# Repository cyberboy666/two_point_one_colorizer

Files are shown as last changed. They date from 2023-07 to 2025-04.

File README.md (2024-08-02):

# two_point_one_colorizer

### analog video colorize effect - adapted from a rob schafer design



- this circuit is distributed by __UNDERSCORES__ - _an open video hardware label_ : it is available to purchase - as a pcb, kit or assembled unit - at [underscores.shop](https://underscores.shop/two_point_one_colorizer/)
- the schematic for the circuit can be found [here](/hardware/schematic.pdf)
- the pcb gerber files for the lastest version can be found [here](/hardware/gerber_latest.zip)
- interactive BOM is [here](https://htmlpreview.github.io/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)
- consider [donating](https://opencollective.com/underscores) to the underscores project to help us continue creating for the commons

## demo video

(https://videos.scanlines.xyz/w/naCDtL88vypcoSo1NTCry6)

## background

<details>
<summary>background</summary>

Rob Schafer designed the original version of this circuit and shared it online in 2020.

It was updated and adapted to pcb by cyberboy666 as open-source hardware with help from the scanlines community – changes included adding PAL, extra color controls and switching to parts that are cheaper & more available









robs original circuit,  effect shown and the schematic here 

</details>
  
# documentation

this project is fully _open-source hardware_ - all the files required to build it are included in this repo for free. if you have the time and/or skill you can contribute back by collaborating on / testing new designs, improving these docs, making demo videos/other creative content etc. you can also support the project financially by [donating](https://opencollective.com/underscores) directing, or purchasing through the [web shop](https://underscores.shop).

depending on whether you are going fully diy or buying an assembled and tested unit, some of the following guides will be relavent to you. the flow would be:

## ordering parts

<details><summary><b>parts sourcing guide (w/ notes on pcb fabracation )</b> - start here if you are building fully from scatch or have purchased a pcb</summary>

i try to source all the parts i can from either:
- [tayda](https://www.taydaelectronics.com/) ; cheaper for common parts like resistors etc, also good for mechanical parts like switches and buttons
- [mouser](https://www.mouser.de/) ; has lots more options, speciality video ic's, can sometimes cost more (free shipping on orders over 50euros)
- other ; ocationally there will be parts which will need to be sourced elsewhere - usaully either aliexpress, ebay or amazon etc...

take a look at the [full_bom](/hardware/bom/full_bom.csv) for this project to see where i am sourcing each part from

## import into tayda

- go to the [tayda quick order](https://www.taydaelectronics.com/quick-order/) and in bottom corner choose _add from file_
- select the file [tayda_bom.csv](./hardware/bom/tayda_bom.csv) in the BOM folder (you will have to download it first or clone this repo)
- after importing select _add to cart_
- __NOTE:__ the minimum value for resistors is 10, so you may need to modify these values to add to cart (or if they are already modified here you will need to see the  full_bom for actual part QTY) 

- OPTIONAL: it is a good idea to add some dip-ic sockets and 2.54pin headers/sockets to your tayda order if you dont have them around already
  
## import into mouser

- go to [mouser bom tool](https://nz.mouser.com/Bom/) and click _upload spreadsheet_
- select the file [mouser_bom.csv](./hardware/bom/mouser_bom.csv) in this folder (you will have to download it first or clone this repo), then _upload my spreadsheet_ and _next_
- ensure that __Mouser Part Number__ is selected in the dropdown above the first row, then _next_, _process_
- if everything looks correct can now put _add to basket_

# ordering pcbs

you can support this project by buying individual pcbs from the [shop](https://underscores.shop). if you would rather have pcbs fabricated from gerbers directly the file you need is [here](/hardware/gerber_latest.zip)

- i get my pcbs fabricated from [jlcpcb](https://cart.jlcpcb.com/quote) - 5 is the minumum order per design
- upload the zip file with the `add gerber file` button
- the default settings are mostly fine - set the __PCB Qty__ and __PCB Color__ settings (you can check that the file looks correct with pcb veiwer)
- it may be best to combine orders with other pcbs you want to have fab'd since the shipping can cost more than the items - also orginising group buys is a good way to distribute the extra pcbs /costs 
  
i often use jlcpcb because they are reliable, cheap and give you an option of colours. remember though that the cheapest Chinese fab houses are not always the most ethical or environmently friendly - if you can afford it consider supporting local companies. 

  </details>
  
## assembly guide
  
<details><summary><b>assembly guide</b> - start here if you have purchased a diy kit</summary>

## interactive BOM for build guiding

follow this link to view the [interactive BOM](https://htmlpreview.github.io/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)

## general solder advice

- remember to heat pad first (2-3seconds), then add solder, then continue to heat (1-2seconds)

- Checkout the web-comic [soldering is easy](https://mightyohm.com/files/soldercomic/FullSolderComic_EN.pdf) for more soldering advice

## general order of assembly

- in general while assembling i start placing resistors and capacitors first. placing 5 - 10 components at a time and then flipping the board to solder them and trim the legs etc.
- next i would do diodes, transistors and ic's - taking care that these are placed in the right direction (using a ic socket can be useful)
- finally i place the interface parts - rca jacks, power jack, pots and switches - make sure these have lots of solder on for structural stablity

</details>

## operating guide
  
<details><summary><b>operating guide</b> - start here if you have purchased an assembled unit</summary>



To set up using the circuit plug an active video source into composite video input and a display into composite video output (test input/outputs by toggling signal bypass switch first to ensure they are working as expected)

Next plug in a 5v center-positive power supply into the 2.1mm barrel jack connector – I like to use a usb wall charger for this – and toggle off the bypass

Adjusting the level knobs should change the resulting image – adjusting the three color knobs and one color switch should set the color and shade for that level

The color_both in middle should off-set resulting color of both sides at once. Playing with format and alternating lines slide switches can help achieve glitching and out of spec colors also

</details>

### more info

<details><summary><b>how the circuit works</b></summary>
  
[coming soon]
                                                                                                                             
</details>

<details><summary><b>contributing guide</b></summary>
  
if you would like to contribute back to these projects in some way but dont know how the best thing (for now) would be to reach out to me directly ( tim@cyberboy666.com or @cyberboy666 on scanlines forum) - i will be happy to help
  
</details>

## credits & more info

This circuit is distributed through UNDERSCORES – open video hardware label – visit [underscores.shop](https://underscores.shop) for more info

The pcb was designed using KICAD , the booklet was created in LibreOffice Draw

Everything from gerbers, cad files, panels and documentation is freely available online and distributed under CC-BY-SA / open-source licenses – help us contribute to the commons !

Ask any questions or start discussions related to this project on the [scanlines.xyz](https://scanlines.xyz) forum – an online community space dedicated to diy av / electronic media art

You can contact me directly at tim (at) cyberboy666 (dot) com 
Please get in touch if you are interested in hosting a workshop !



Thanks to Rob Schafer for sharing your designs and knowledge. to Bastien Lavaud for circuit advice, always. To Ben Caldwell for project advice. To everyone who has or will contribute ♥♥♥

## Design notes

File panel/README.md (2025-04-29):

# enclosure guide

we now offer two kinds of enclosures for this project:

- __stand-alone enclosure__ - made from a front and back panel, plus screws and standoffs



- __eurorack enclosure__ - made from just a front panel, plus screws and standoffs to mount in a eurorack case



you can support these projects by getting enclosure kits directly through [underscores.shop](https://underscores.shop) - [standalone](https://underscores.shop/product/standalone-enclosure-kit-for-two_point_one_colorizer/) and [eurorack](https://underscores.shop/product/eurorack-kit-for-two_point_one_colorizer/) - _if ordered with an assembled unit we will also assemble the enclosure for you also_

# diy part sourcing

## panel fabrication

included in this repo are the cad files needed to create your own panels. they are designed in kicads pcbnew - so open the `.kicad_pcb` file to edit them directly. 

you can also use the exported `gerber` files (here they are combined in `.zip`) to get panels fabricated in __fr4__ at a pcb house like the ones we sell. (these usually have a minimum order of 5 or 10)  

another option for diy fabrication is using a lasercutter to cut the panels in wood or acrylic. this is what i do when prototyping panels so you should find some exports in `svg` or `dxf` that are laser ready. _note that the `edgecut` layer is for cutting out and the `silkscreen` layer is for the panel markings. you may need to edit these files or export directly from pcbnew to suit the cutter you are using_

it would also be possible to import these panel files into a sketch in 3d cad program like __freecad__ to create a 3d enclosure for 3d printing... however this is not something i have files prepared for

## 3d printing

i use some custom modelled switch and pot caps for my enclosure kits. you can print these yourself or upload them to a 3d printing fabrication service.

## enclosure kit BOM

things like screws and standoffs can be sourced from lots of places. i will link my source as an example although these links often expire. you could even 3d print your own standoffs from the _id/od_ and length (inner diameter 3.2mm, outer diameter 5mm)

### standalone enclosure

item | source
--- | ---
Front panel | [two_point_one_colorizer_v1_0_0_default_panel.zip](https://github.com/cyberboy666/two_point_one_colorizer/blob/main/panel/default_panel/two_point_one_colorizer_v1_0_0_default_panel.zip)
Back panel | [back_panel.zip](https://github.com/cyberboy666/two_point_one_colorizer/blob/main/panel/back_panel/back_panel.zip)
Rubber feet x4 | [aliexpress](https://www.aliexpress.com/item/1005005287385986.html?pdp_ext_f=%7B%22sku_id%22:%2212000032498489269%22%7D)
Pot cap x9 | 3d printed from [stl file](https://github.com/cyberboy666/enclosure_kit_commons/blob/main/cap_pot_6mm_shaft/cap_pot_star_single_r2.8.stl)
Switch cap x2 | 3d printed from [stl file](https://github.com/cyberboy666/enclosure_kit_commons/blob/main/cap_switch_1P2T_tayda_A-659/cap_switch_1P2T_tayda_A-659_single-cap.stl)
M3-25mm screw x4 | [aliexpress](https://www.aliexpress.com/item/1005002364189187.html?pdp_ext_f=%7B%22sku_id%22:%2212000020354274907%22%7D)
M3 nut x4 | [aliexpress](https://www.aliexpress.com/item/1005007502691265.html?pdp_ext_f=%7B"sku_id":"12000041089836836"%7D)
m3-12mm standoff x4 (front) | [aliexpress](https://www.aliexpress.com/item/1005003086579258.html?pdp_ext_f=%7B"sku_id":"12000023995222163"%7D)
m3-5mm standoff x4 (back) | [aliexpress](https://www.aliexpress.com/item/1005003086579258.html?pdp_ext_f=%7B"sku_id":"12000023995222156"%7D)

### eurorack enclosure

item | source
--- | ---
Eurorack front panel | [two_point_one_colorizer_v1_0_0_eurorack_panel.zip](https://github.com/cyberboy666/two_point_one_colorizer/blob/main/panel/eurorack_panel/two_point_one_colorizer_v1_0_0_eurorack_panel.zip)
Eurorack 16pin power converter | [eurorack_to_usb_passive_mk_i.zip](https://github.com/cyberboy666/enclosure_kit_commons/blob/main/eurorack_power-adapters/eurorack_to_usb_passive/eurorack_to_usb_passive_mk_i.zip) gerber
Vertical barrel jack | [tayda](https://www.taydaelectronics.com/dc-power-jack-2-1mm-round-type-panel-mount-1.html)
Pot cap x2 | 3d printed from [stl file](https://github.com/cyberboy666/enclosure_kit_commons/blob/main/cap_pot_6mm_shaft/cap_pot_star_single_r2.8.stl)
Switch cap x2 | 3d printed from [stl file](https://github.com/cyberboy666/enclosure_kit_commons/blob/main/cap_switch_1P2T_tayda_A-659/cap_switch_1P2T_tayda_A-659_single-cap.stl)
M3-25mm screw x4 | [aliexpress](https://www.aliexpress.com/item/1005002364189187.html?pdp_ext_f=%7B%22sku_id%22:%2212000020354274907%22%7D)
M3 nut x4 | [aliexpress](https://www.aliexpress.com/item/1005007502691265.html?pdp_ext_f=%7B"sku_id":"12000041089836836"%7D)
m3-12mm standoff x4 (front) | [aliexpress](https://www.aliexpress.com/item/1005003086579258.html?pdp_ext_f=%7B"sku_id":"12000023995222163"%7D)
m3-8mm screw x4 | [aliexpress](https://www.aliexpress.com/item/1005002364189187.html?pdp_ext_f=%7B%22sku_id%22:%2212000020354274900%22%7D)

## eurorack power jack placement

many underscores circuits take 5v from a [horizontal mounted dc barrel jack](https://www.taydaelectronics.com/dc-power-jack-2-1mm-barrel-type-pcb-mount.html) which is good for standalone circuits powered from the side. however for eurorack mounted circuits it can be easier to plug in power from behind. in this case we can use a [vertical dc socket](https://www.taydaelectronics.com/dc-power-jack-2-1mm-round-type-panel-mount-1.html) instead. for these sockets the longer pin is GND which goes closest to the edge of pcb.

Screenshot from 2025-04-29 11-19-55



## enclosure assembling

these enclosures are assemlbed by creating a stack of front-panel -> circuit -> back-panel using the screws and standoffs. where the front standoffs go between front panel and pcb and back standoff go between back panel and pcb. the m3 hex holds it together from the bottom.

i find it easiest to hold circuit on its side and work around one screw at a time:

- first place the front standoff between front panel and pcb
- then put the screw through holding them together
- next place back standoff on screw followed by back panel and hex
- then repeat for other 3 corners

tweezers can be helpful to pick and place the standoffs and also to tighten the m3 hexs

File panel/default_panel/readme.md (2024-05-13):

# two_point_one_colorizer default_panel notes

- the mounting holes fit m3 screws
- 25mm screws will fit front_panel, pcb and back_plate
- the front_panel mounts to pcb with 12mm standoffs
- small slide switches to set pal/ntsc are too low to be hand switched with panel on - can still be set with tool such as screwdriver
- the default potentiometers in underscores BOMs have 12mm shaft lengths - consider replacing these with >17mm shaft length alternatives if you plan to use it with a panel

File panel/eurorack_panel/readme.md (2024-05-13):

# two_point_one_colorizer eurorack_panel notes

- the mounting holes fit m3 screws
- the panel mounts to pcb with 12mm standoffs
- this circuit is powered by 5v on 2.1_barrel_jack - a [vertical jack](https://www.taydaelectronics.com/dc-power-jack-2-1mm-round-type-panel-mount-1.html) soldered to bottom of pcb will allow powering from within eurorack case
- small slide switches to set pal/ntsc are too low to be hand switched with panel on - can set with tool such as screwdriver
- this panel is 20HP
- the default potentiometers in underscores BOMs have 12mm shaft lengths - consider replacing these with >17mm shaft length alternatives if you plan to use it with a panel

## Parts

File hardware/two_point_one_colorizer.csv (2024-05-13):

Reference | Quantity | Value | Footprint | Datasheet
C1 C3 | 2 | 33p | Capacitor_THT:C_Disc_D4.7mm_W2.5mm_P5.00mm
C14 | 1 | 100p | Capacitor_THT:C_Disc_D4.7mm_W2.5mm_P5.00mm
C18 C19 C20 C21 | 4 | 10p | Capacitor_THT:C_Disc_D4.7mm_W2.5mm_P5.00mm
C2 C5 C6 C7 C8 C9 C10 C11 C12 C13 C15 C16 C17 | 13 | 0.1u | Capacitor_THT:C_Disc_D4.7mm_W2.5mm_P5.00mm
C4 | 1 | 10u | Capacitor_THT:CP_Radial_D5.0mm_P2.50mm
D1 | 1 | 1n914 | Diode_THT:D_DO-41_SOD81_P7.62mm_Horizontal
J1 | 1 | Barrel_Jack | Connector_BarrelJack:BarrelJack_Horizontal
J2 J5 | 2 | rca | lib_fp:tht_vertical_rca | ~
Q1 | 1 | 2N3904 | Package_TO_SOT_THT:TO-92L_HandSolder | https://www.fairchildsemi.com/datasheets/2N/2N3904.pdf
R1 R5 R8 | 3 | 75 | Resistor_THT:R_Axial_DIN0207_L6.3mm_D2.5mm_P7.62mm_Horizontal
R12 | 1 | 680 | Resistor_THT:R_Axial_DIN0207_L6.3mm_D2.5mm_P7.62mm_Horizontal
R15 | 1 | 12k | Resistor_THT:R_Axial_DIN0207_L6.3mm_D2.5mm_P7.62mm_Horizontal
R17 R18 | 2 | 18k | Resistor_THT:R_Axial_DIN0207_L6.3mm_D2.5mm_P7.62mm_Horizontal
R19 R20 | 2 | 22k | Resistor_THT:R_Axial_DIN0207_L6.3mm_D2.5mm_P7.62mm_Horizontal
R2 R4 | 2 | 1m | Resistor_THT:R_Axial_DIN0207_L6.3mm_D2.5mm_P7.62mm_Horizontal
R23 R24 | 2 | 82k | Resistor_THT:R_Axial_DIN0207_L6.3mm_D2.5mm_P7.62mm_Horizontal
R10 R13 R14 R25 R26 | 5 | 10k | Resistor_THT:R_Axial_DIN0207_L6.3mm_D2.5mm_P7.62mm_Horizontal
R27 R28 R29 R30 | 4 | 2.7k | Resistor_THT:R_Axial_DIN0207_L6.3mm_D2.5mm_P7.62mm_Horizontal
R3 | 1 | 5.1k | Resistor_THT:R_Axial_DIN0207_L6.3mm_D2.5mm_P7.62mm_Horizontal
R16 R33 R35 | 3 | 1.5k | Resistor_THT:R_Axial_DIN0207_L6.3mm_D2.5mm_P7.62mm_Horizontal
R34 R36 | 2 | 3.3k | Resistor_THT:R_Axial_DIN0207_L6.3mm_D2.5mm_P7.62mm_Horizontal
R6 | 1 | 100 | Resistor_THT:R_Axial_DIN0207_L6.3mm_D2.5mm_P7.62mm_Horizontal
R7 R11 R31 R32 | 4 | 1k | Resistor_THT:R_Axial_DIN0207_L6.3mm_D2.5mm_P7.62mm_Horizontal
R9 | 1 | 680k | Resistor_THT:R_Axial_DIN0207_L6.3mm_D2.5mm_P7.62mm_Horizontal
RV1 | 1 | 20k_pot | lib_fp:Potentiometer_Vertical_Large
RV2 RV3 RV4 RV5 RV6 RV7 | 6 | 10k_pot | lib_fp:Potentiometer_Vertical_Large
RV8 RV9 | 2 | 5k_pot | lib_fp:Potentiometer_Vertical_Large
SW1 SW2 | 2 | SPDT_slide | lib_fp:spdt_slide_switch_small_tayda
SW3 SW4 | 2 | SPDT | lib_fp:mini_toggle_switch_tayda
SW5 | 1 | SW_DPDT_x2 | lib_fp:dpdt_mini_toggle_switch_tayda
U1 | 1 | CD4069 | Package_DIP:DIP-14_W7.62mm_LongPads | http://www.intersil.com/content/dam/Intersil/documents/cd40/cd4069ubms.pdf
U2 | 1 | LM317 | Package_TO_SOT_THT:TO-220-3_Vertical | http://www.ti.com/lit/ds/symlink/lm317.pdf
U3 | 1 | CD4053 | Package_DIP:DIP-16_W7.62mm_LongPads | http://www.intersil.com/content/dam/Intersil/documents/cd40/cd4051bms-52bms-53bms.pdf
U4 | 1 | CD4013 | Package_DIP:DIP-14_W7.62mm_LongPads | http://www.onsemi.com/pub/Collateral/MC14013B-D.PDF
U5 | 1 | 74HC4538 | Package_DIP:DIP-16_W7.62mm_LongPads | https://assets.nexperia.com/documents/data-sheet/HEF4538B.pdf
U6 | 1 | LM1881 | lib_fp:DIP-SOIC-8
U7 | 1 | 74HC86 | Package_DIP:DIP-14_W7.62mm_LongPads | http://www.ti.com/lit/gpn/sn74HC86
U8 | 1 | LM393 | Package_DIP:DIP-8_W7.62mm_LongPads | http://www.ti.com/lit/ds/symlink/lm393-n.pdf
U9 U10 | 2 | 74LS123 | Package_DIP:DIP-16_W7.62mm_LongPads | http://www.ti.com/lit/gpn/sn74LS221
Y1 | 1 | 3.57Mhz_crystal | Crystal:Crystal_HC49-4H_Vertical
Y2 | 1 | 4.43Mhz_crystal | Crystal:Crystal_HC49-4H_Vertical

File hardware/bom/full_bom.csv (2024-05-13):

sku | qty | ref | val | vendor
A-525 | 2 | C1 C3 | 33p | tayda
A-531 | 1 | C14 | 100p | tayda
A-1341 | 4 | C18 C19 C20 C21 | 10p | tayda
A-4008 | 13 | C2 C5 C6 C7 C8 C9 C10 C11 C12 C13 C15 C16 C17 | 0.1u | tayda
A-3931 | 1 | C4 | 10u | tayda
A-615 | 1 | D1 | 1n914 | tayda
A-4118 | 1 | J1 | Barrel_Jack | tayda
490-RCJ-024 | 2 | J2 J5 | rca | mouser
A-111 | 1 | Q1 | 2N3904 | tayda
A-2193 | 3 | R1 R5 R8 | 75 | tayda
A-2281 | 1 | R12 | 680 | tayda
A-2327 | 1 | R15 | 12k | tayda
A-2207 | 2 | R17 R18 | 18k | tayda
A-2284 | 2 | R19 R20 | 22k | tayda
A-2277 | 2 | R2 R4 | 1m | tayda
A-2338 | 2 | R23 R24 | 82k | tayda
A-2203 | 5 | R10 R13 R14 R25 R26 | 10k | tayda
A-2626 | 4 | R27 R28 R29 R30 | 2.7k | tayda
A-2188 | 1 | R3 | 5.1k | tayda
A-2202 | 3 | R16 R33 R35 | 1.5k | tayda
A-2607 | 2 | R34 R36 | 3.3k | tayda
A-2245 | 1 | R6 | 100 | tayda
A-2200 | 4 | R7 R11 R31 R32 | 1k | tayda
A-2192 | 1 | R9 | 680k | tayda
A-1872 | 1 | RV1 | 20k_pot | tayda
A-5531 | 6 | RV2 RV3 RV4 RV5 RV6 RV7 | 10k_pot | tayda
A-1870 | 2 | RV8 RV9 | 5k_pot | tayda
A-659 | 2 | SW1 SW2 | SPDT_slide | tayda
A-4567 | 2 | SW3 SW4 | SPDT | tayda
A-4568 | 1 | SW5 | SW_DPDT_x2 | tayda
A-882 | 1 | U1 | CD4069 | tayda
A-177 | 1 | U2 | LM317 | tayda
A-1151 | 1 | U3 | CD4053 | tayda
A-556 | 1 | U4 | CD4013 | tayda
595-CD74HC4538E | 1 | U5 | 74HC4538 | mouser
926-LM1881MX/NOPB | 1 | U6 | LM1881 | mouser
595-SN74HC86NE4 | 1 | U7 | 74HC86 | mouser
A-023 | 1 | U8 | LM393 | tayda
595-SN74LS123N | 2 | U9 U10 | 74LS123 | mouser
A-238 | 1 | Y1 | 3.57Mhz_crystal | tayda
520-HCU443-20X | 1 | Y2 | 4.43Mhz_crystal | mouser

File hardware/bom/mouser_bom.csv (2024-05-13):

sku | qty | ref | val | vendor
490-RCJ-024 | 2 | J2 J5 | rca | mouser
595-CD74HC4538E | 1 | U5 | 74HC4538 | mouser
926-LM1881MX/NOPB | 1 | U6 | LM1881 | mouser
595-SN74HC86NE4 | 1 | U7 | 74HC86 | mouser
595-SN74LS123N | 2 | U9 U10 | 74LS123 | mouser
520-HCU443-20X | 1 | Y2 | 4.43Mhz_crystal | mouser

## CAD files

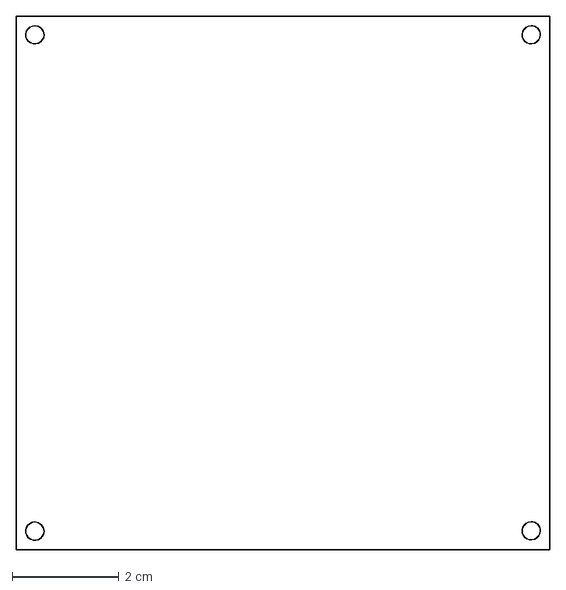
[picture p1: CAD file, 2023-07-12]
panel/back_panel/back_panel-Edge_Cuts.dxf
10.0 x 10.0 cm

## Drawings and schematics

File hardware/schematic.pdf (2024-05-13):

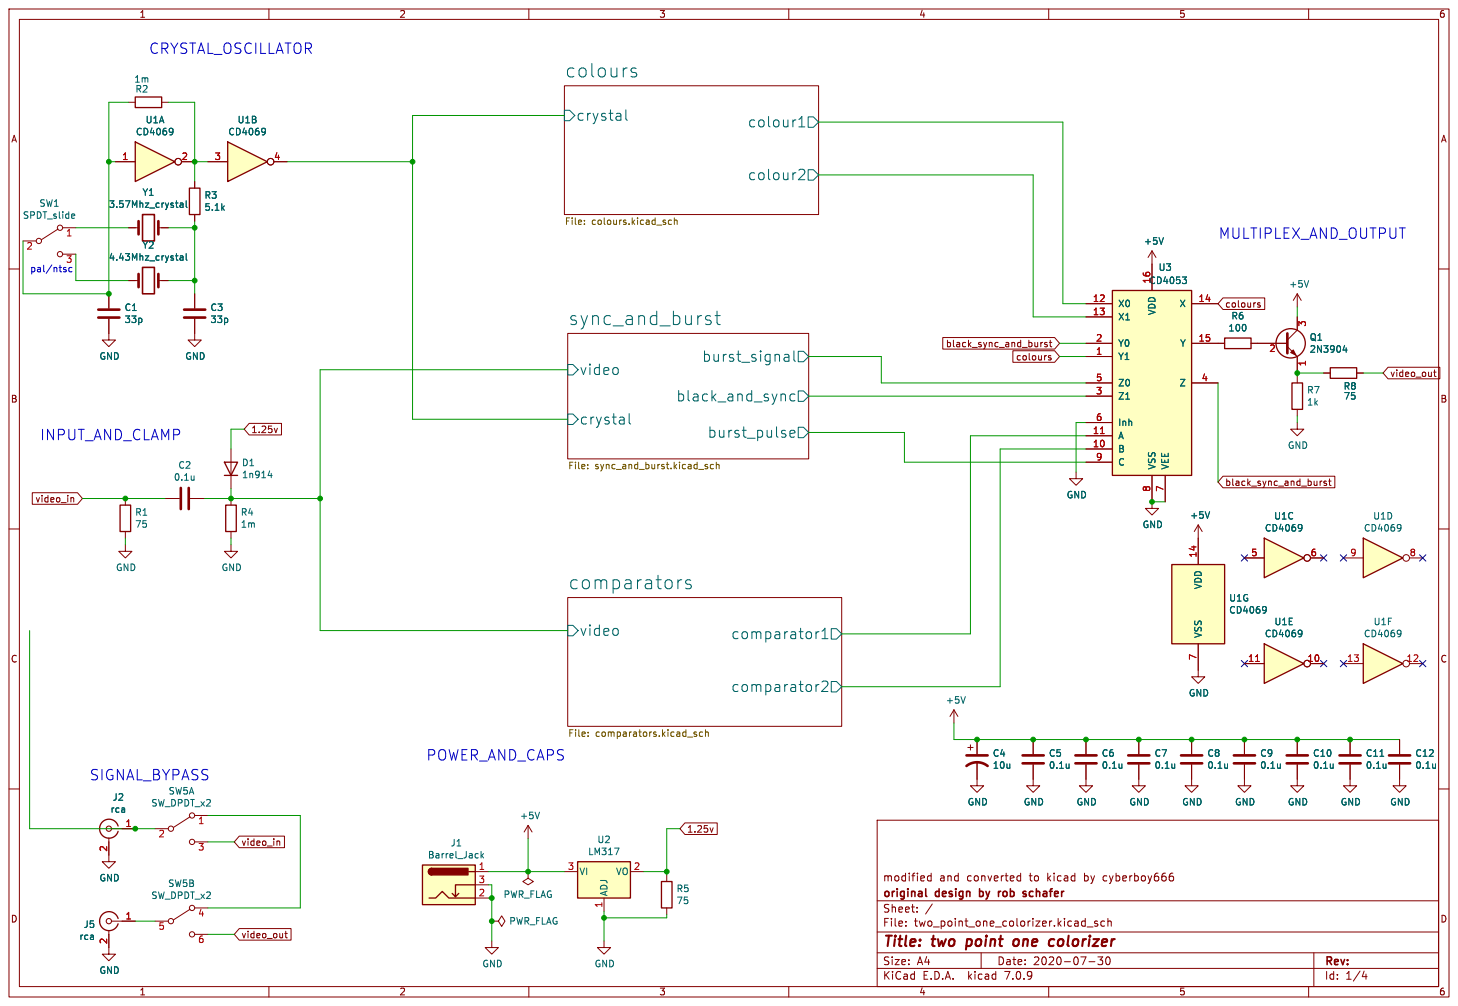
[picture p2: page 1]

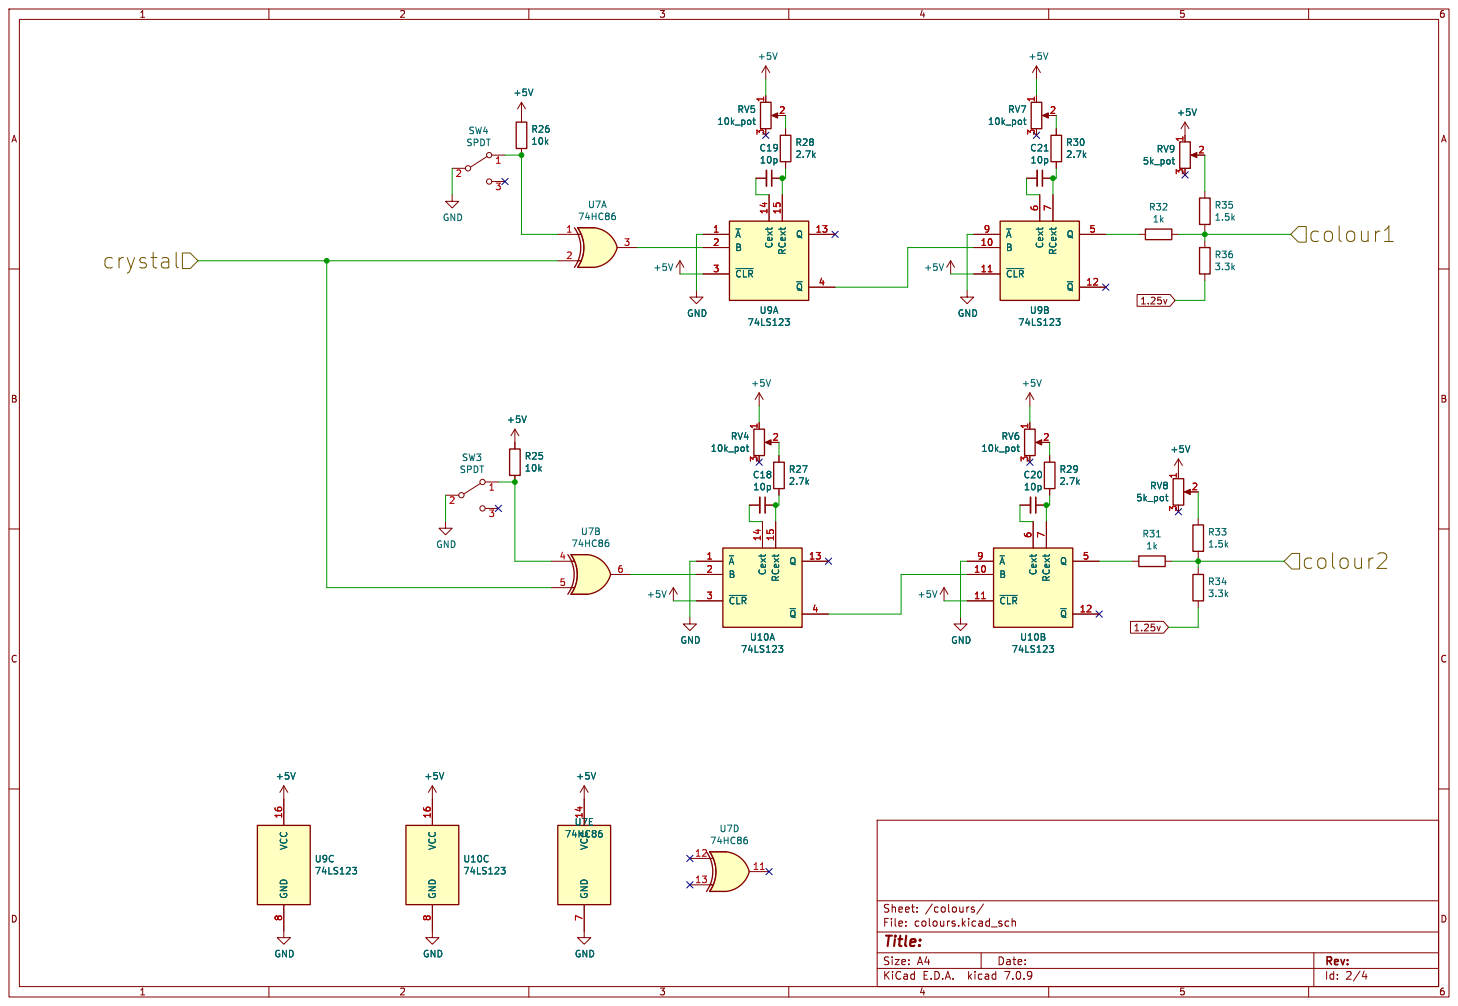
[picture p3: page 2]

Id: 2/4 Title: File: colours.kicad_sch Sheet: /colours/

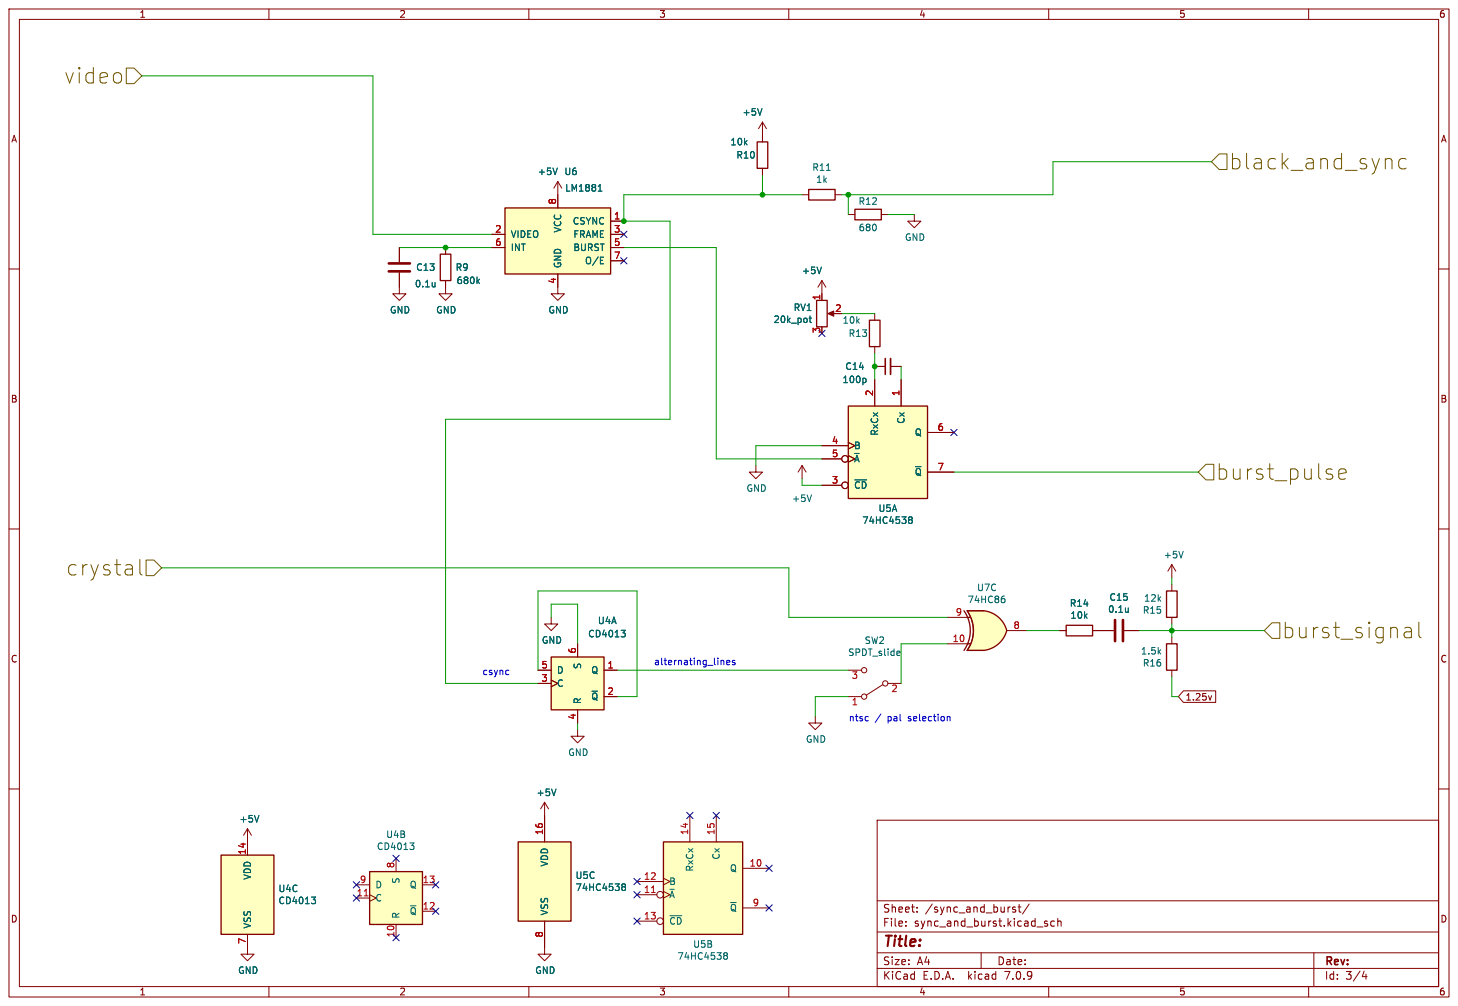
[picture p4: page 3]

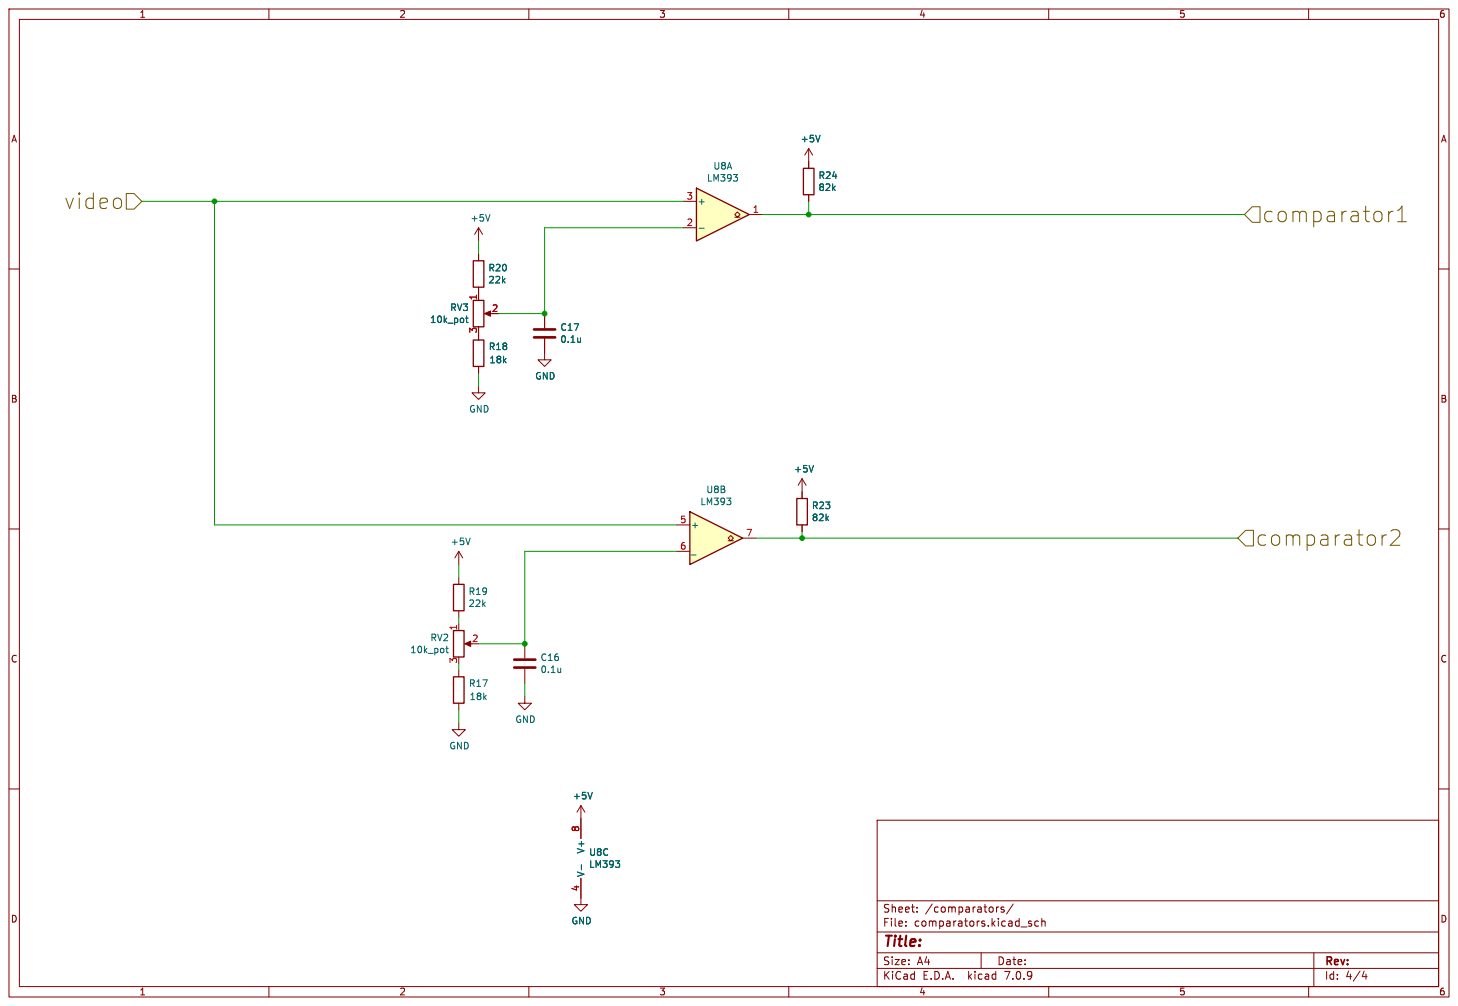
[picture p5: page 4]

Id: 4/4 Title: File: comparators.kicad_sch Sheet: /comparators/

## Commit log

2022-01-10 migrate repo
    [colours.sch, comparators.sch, sync_and_burst.sch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]
2023-07-12 add panel stuff
    [back_panel-Edge_Cuts.dxf, back_panel.kicad_pcb, back_panel.kicad_sch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]
2024-04-27 getting ready to release
    [colours.kicad_sch, comparators.kicad_sch, default_panel-Edge_Cuts.dxf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]
2024-05-13 export ffor v1 release
    [default_panel.kicad_pcb, eurorack_panel.kicad_pcb, two_point_one_colorizer copy.kicad_pcb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]
2024-05-13 update panels
    [default_panel.kicad_pcb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]
